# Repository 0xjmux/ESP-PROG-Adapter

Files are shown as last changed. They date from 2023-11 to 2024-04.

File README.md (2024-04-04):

# ESP32 Firmware Debugging, as Easy as Possible





* [My blog post about this project](https://jacobbokor.com/posts/esp-jtag-adapter/)
* [Look ma, I was featured on Hackaday!](https://hackaday.com/2024/04/03/esp-prog-adapter-makes-your-esp32-tinkering-seamless/)

One of the things I've noticed in a lot of beginner ESP32 PCBs is a lack of hardware debugging interfaces, which is understandable since setting up JTAG can be a bit confusing when you're first exposed to it. This project's goal is to make using JTAG and connector-less footprints on your PCBs as easy and cheap as possible. 

#### To get started, all you need is: 
1. An ESP-Prog, Espressif's cheap and flexible UART and JTAG adapter - [Aliexpress, ~$11 US](https://s.click.aliexpress.com/e/_DnkCFmz)
1. SOIC-8 Clip programming cable for SOICbite - [Aliexpress, ~$3](https://www.aliexpress.us/item/3256805091794484.html)
1. My adapter PCB and [connectors](#Components) ordered from your favorite PCB house ([Gerbers found under releases](https://github.com/0xjmux/ESP-PROG-Adapter/releases)) - ~$6 with connectors
1. My Kicad library (found under [ESP-EZ-Debug-KicadLib/](./ESP-EZ-Debug-KicadLib)) to easily include connector-less footprints in your Kicad designs. 

## ESP-Prog Programming Cable Adapter

Simple PCB that sits on top of the ESP-Prog to use the SOICbite and Tag-Connect TC2050-IDC adapters to program and debug ESP-based projects.
 
<p align="center">
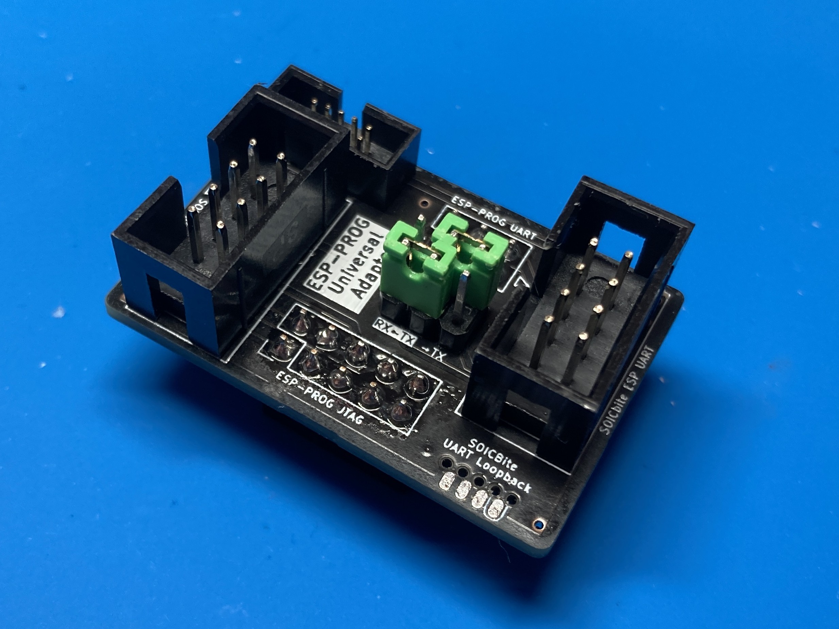
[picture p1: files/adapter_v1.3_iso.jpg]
ISO view of adapter

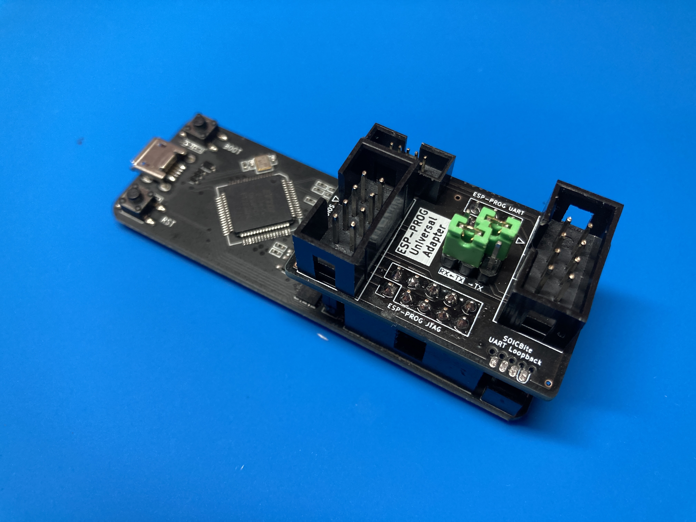
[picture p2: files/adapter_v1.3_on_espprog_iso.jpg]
ISO view of adapter on ESP-Prog

</p>

I originally made this adapter because I was in need of a hardware debugging solution for my ESP-based projects, and was tired of the dupont wire mess I needed to connect my programming cable to my JTAG adapter. 
 
## Features
* Easily connect your TC-2050-IDC and SOICbite programming cables to the ESP-Prog for JTAG and UART programming. 
    * This enables you to easily integrate component-less programming footprints with your ESP-based projects (and anything else using UART).
* Includes reversible UART TX/RX so if you mess it up on your board, you can easily change it on the adapter!
* Onboard SOICBite "loopback" footprint with TX-RX pins connected, allowing you to easily confirm your adapter's UART is working. 
* Detailed [schematic](files/esp-prog-adapter-v1.3-sch.pdf) containing all info you might need about the adapter, and easy to use schematic symbols (see [jmux-kicad-things](https://github.com/0xjmux/jmux-kicad-things)) for using the connectors in your designs. 

> [!NOTE]
> Schematic, Gerbers, and all other files needed for production and assembly can be found attached to the latest [release!](https://github.com/0xjmux/ESP-PROG-Adapter/releases/latest)

<p align="center">
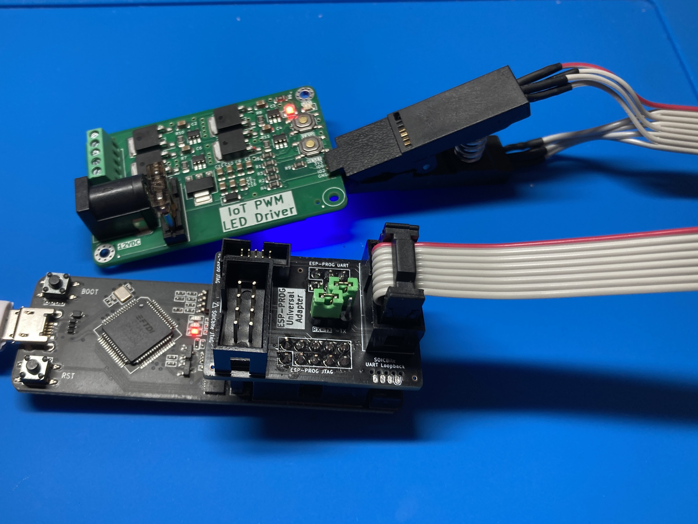
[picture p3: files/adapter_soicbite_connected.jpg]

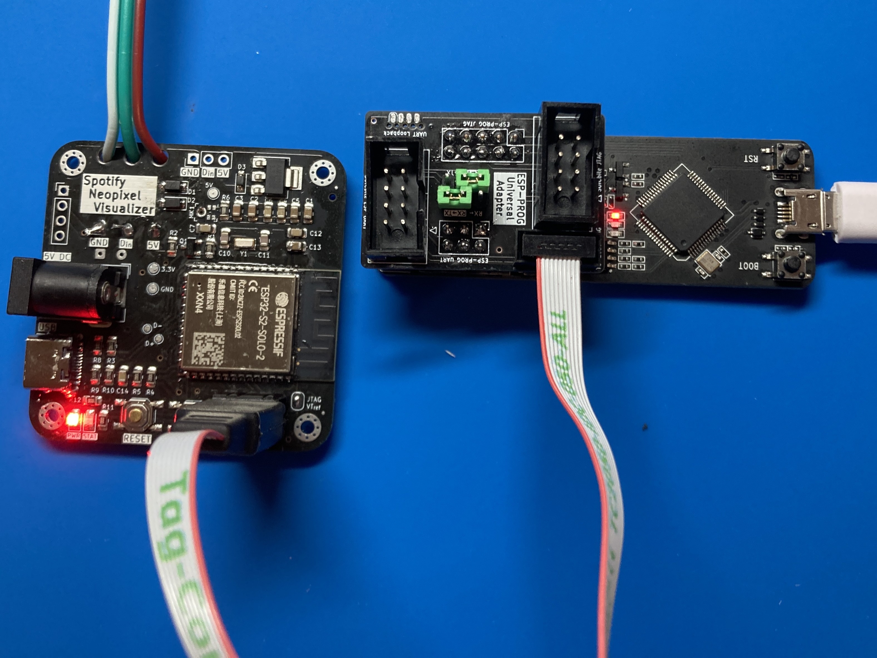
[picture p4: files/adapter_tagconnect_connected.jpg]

<br>SOICBite (left) and Tag-Connect (right) cables connected to target boards using the adapter
</p>

<p align="center">
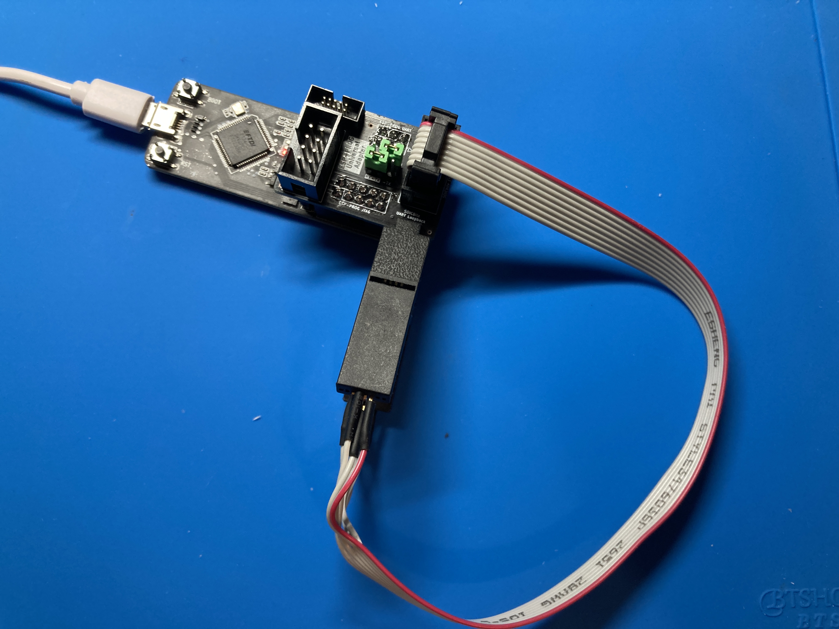
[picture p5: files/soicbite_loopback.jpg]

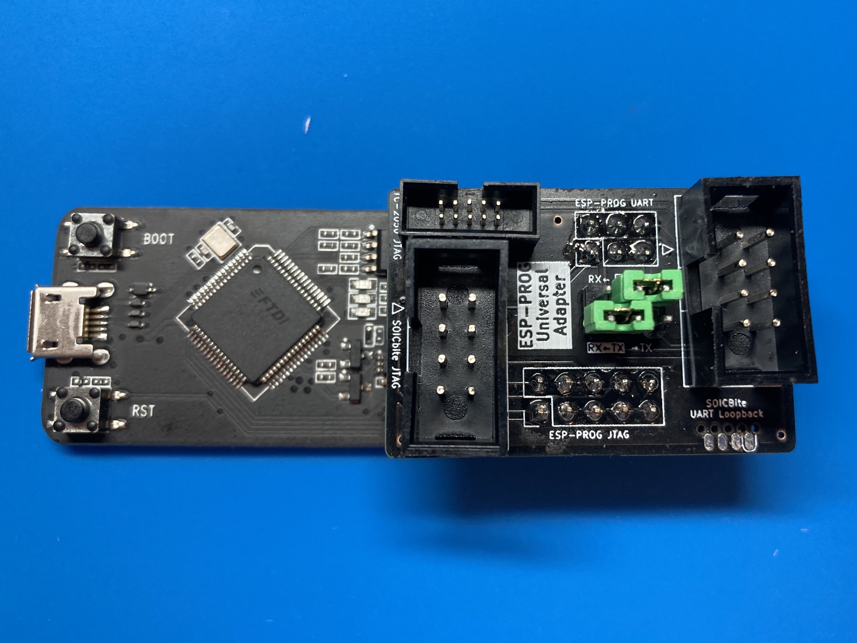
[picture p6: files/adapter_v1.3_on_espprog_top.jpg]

<br>SOICBite UART loopback usage (left) and top view of adapter on ESP-Prog (right)
</p>

## How to Use
* To make using these in your projects as easy as possible, I've created a Kicad library under `ESP-EZ-Debug-KicadLib/`. 
* These schematic symbols follow the [standard pinouts](https://github.com/SimonMerrett/SOICbite/tree/master?tab=readme-ov-file#pin-assignment) for each connector and are designed to be as self-explanatory as possible. There's an image example of connector wiring below, along with `UsageExamples.kicad_sch` so you can directly copy and paste into your designs. 

> [!NOTE]
> For information on installing and using the Kicad library, see [ESP-EZ-Debug-KicadLib/README.md](ESP-EZ-Debug-KicadLib/)

<p align="center">
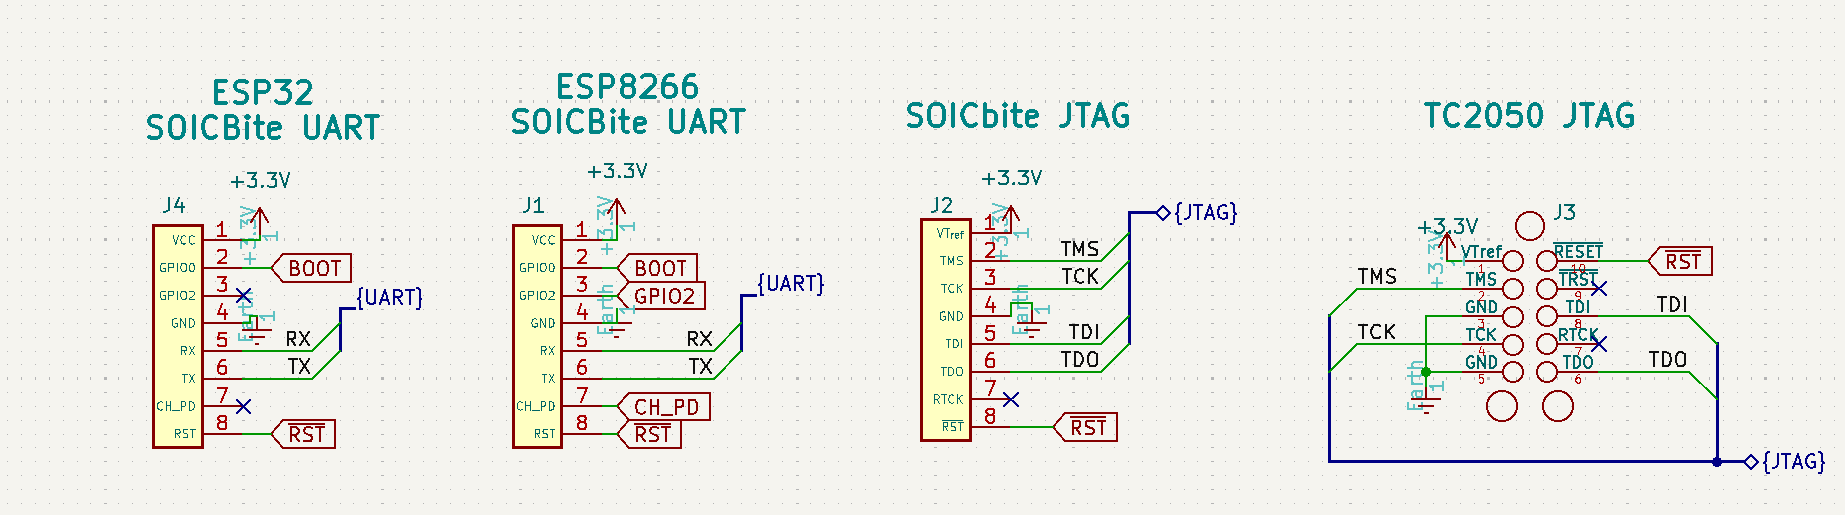
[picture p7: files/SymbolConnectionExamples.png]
<br>
Examples of how to wire up each connector to an ESP32
</p>

#### Pinouts
* The SOICBite UART connector follows the [standard pinout](https://github.com/SimonMerrett/SOICbite/tree/master?tab=readme-ov-file#pin-assignment). There wasn't a JTAG pinout already, so [I contributed one](https://github.com/SimonMerrett/SOICbite/pull/26) - although as of April 2024 it hasn't been merged into the repo. Because it hasn't been merged in, here's a pinout table. 

| Pin | ESP8266 | JTAG |
| --- | --- | ---- |
| 1 | Vcc | Vcc  |
| 2 | GPIO0 | TMS  |
| 3 | GPIO2 | TCK  |
| 4 | GND | GND  |
| 5 | RX | TDI  |
| 6 | TX | TDO  |
| 7 | CH_PD | RTCK |
| 8 | RST | NRST |

#### Software: Setting up Debugging with ESP-IDF and VSCode
* [This configuration note for the ESP-IDF VSCode extension](https://github.com/espressif/vscode-esp-idf-extension/blob/master/docs/DEBUGGING.md) is very helpful for setting up the IDE for hardware debugging
* [Espressif's documentation page on JTAG debugging for the ESP32](https://docs.espressif.com/projects/esp-idf/en/latest/esp32/api-guides/jtag-debugging/index.html#how-it-works)

## Hardware Setup/Soldering
The board comes with optional swappable UART jumpers. If this feature is not needed, simply solder the two solderjumpers (JP5 & JP6) that connect UART normally. 

> [!IMPORTANT]
> You must either bridge the solderjumpers or install the pin headers. If you don't do either, the UART interface won't be connected. 

### Components

| Component | Purpose | LCSC Part # | Link |
|---|---|---|---|
| 2x5P 2.54mm Female Header | ESP-Prog JTAG | C18723056 | [LCSC](https://www.lcsc.com/product-detail/Female-Headers_HanElectricity-2541FV-2x5P_C18723056.html) |
| 2x3P 2.54mm Female Header | ESP-Prog UART | C5298392 | [LCSC](https://www.lcsc.com/product-detail/span-style-background-color-ff0-Female-span-span-style-background-color-ff0-Headers-span_CJT-Changjiang-Connectors-A2541HWV-2x3P_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) |
| 2x5P 1.27mm IDC Header | TC2050 Conector | C2962228 | [LCSC](https://www.lcsc.com/product-detail/IDC-Connectors_XKB-Connectivity-X1270WV-2x05A-6TV01_C2962228.html) |
| 2x4P 2.54mm IDC Header (x2) | SOICBite Connector | C17179451 | [LCSC](https://www.lcsc.com/product-detail/IDC-Connectors_HanElectricity-HY2541WV-N-2x4P_C17179451.html) (x2) |
| 2x3P 2.54mm M Pin Header | Reversible UART Jumpers | C2935918 | [LCSC](https://www.lcsc.com/product-detail/Pin-Headers_DEALON-DZ254R-22-06-63_C2935918.html) |

<br/>
<p align="center" >
<br>
If you found the work I put into this valuable, I'd appreciate if you could buy me a coffee so I can continue devoting time to extensively documenting my projects like this. 
</p>

### Soldering Order
I recommend going from shortest to tallest components, starting on the top side of the PCB. This is a very approachable solder job since everything is THT, but when attaching the headers that connect to the ESP-PROG there is the potential to burn the plastic of the connectors already installed on the top. Here's the order I recommend attaching the components:

1. TC2050 IDC Socket
1. 2x3 Pin header and SOICbite socket(s)
1. Downward facing F pin headers that connect to ESP-PROG

## Versions
### V1.4 - Polishing it up
* All functionality confirmed working.
* PCB updated to clarify assembly and use (text enlarged, dual 1x3 headers for reversible UART changed to single 2x3P using custom symbol).
* Vdd for JTAG and UART disconnected from each other on adapter, allowing different voltage to be used for each.
* Connected nRST line of ESP-PROG (from UART header) to board RESET line on JTAG pinout with solderjumper.
* Default connected solderjumpers changed to default open for Reversible UART, since I anticipate it'll be more used than not. 

<p align="center">
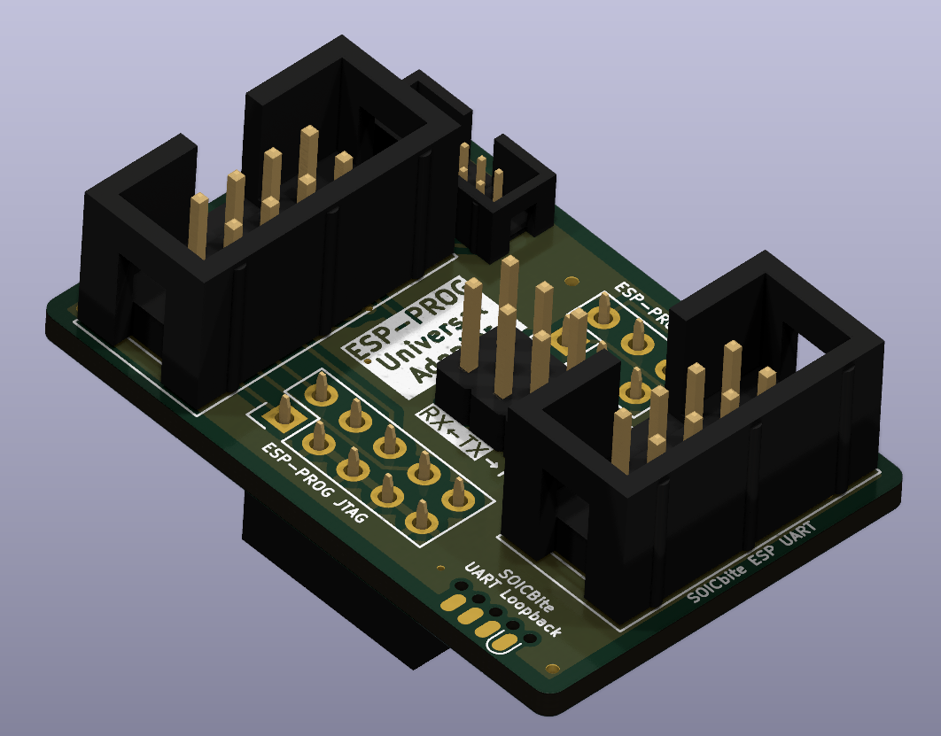
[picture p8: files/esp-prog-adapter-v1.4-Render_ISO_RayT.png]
v1.4 PCB Render ISO angle

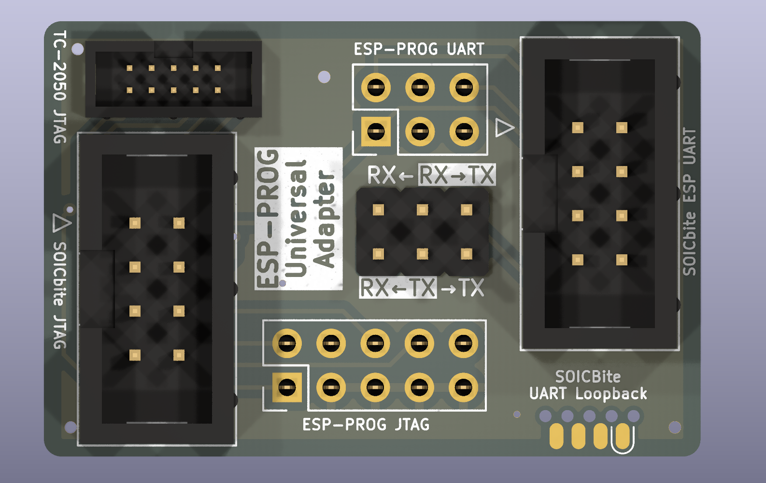
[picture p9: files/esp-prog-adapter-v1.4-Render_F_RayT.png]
v1.4 PCB Render Front

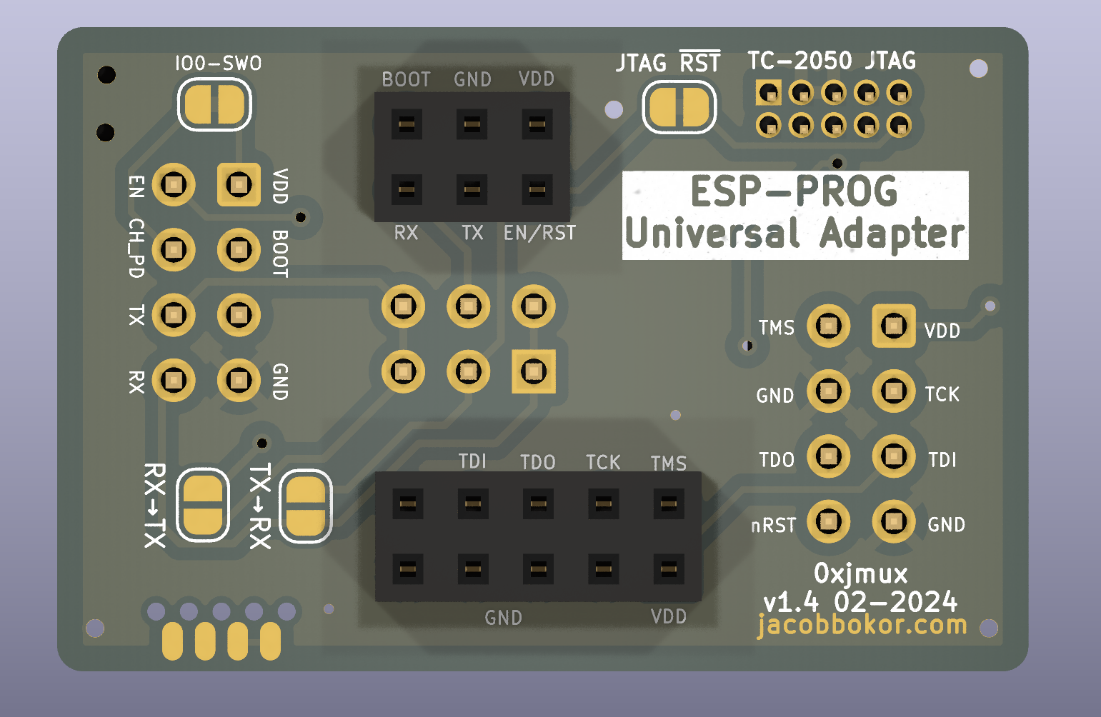
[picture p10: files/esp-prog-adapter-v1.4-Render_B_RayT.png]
v1.4 PCB Render Back

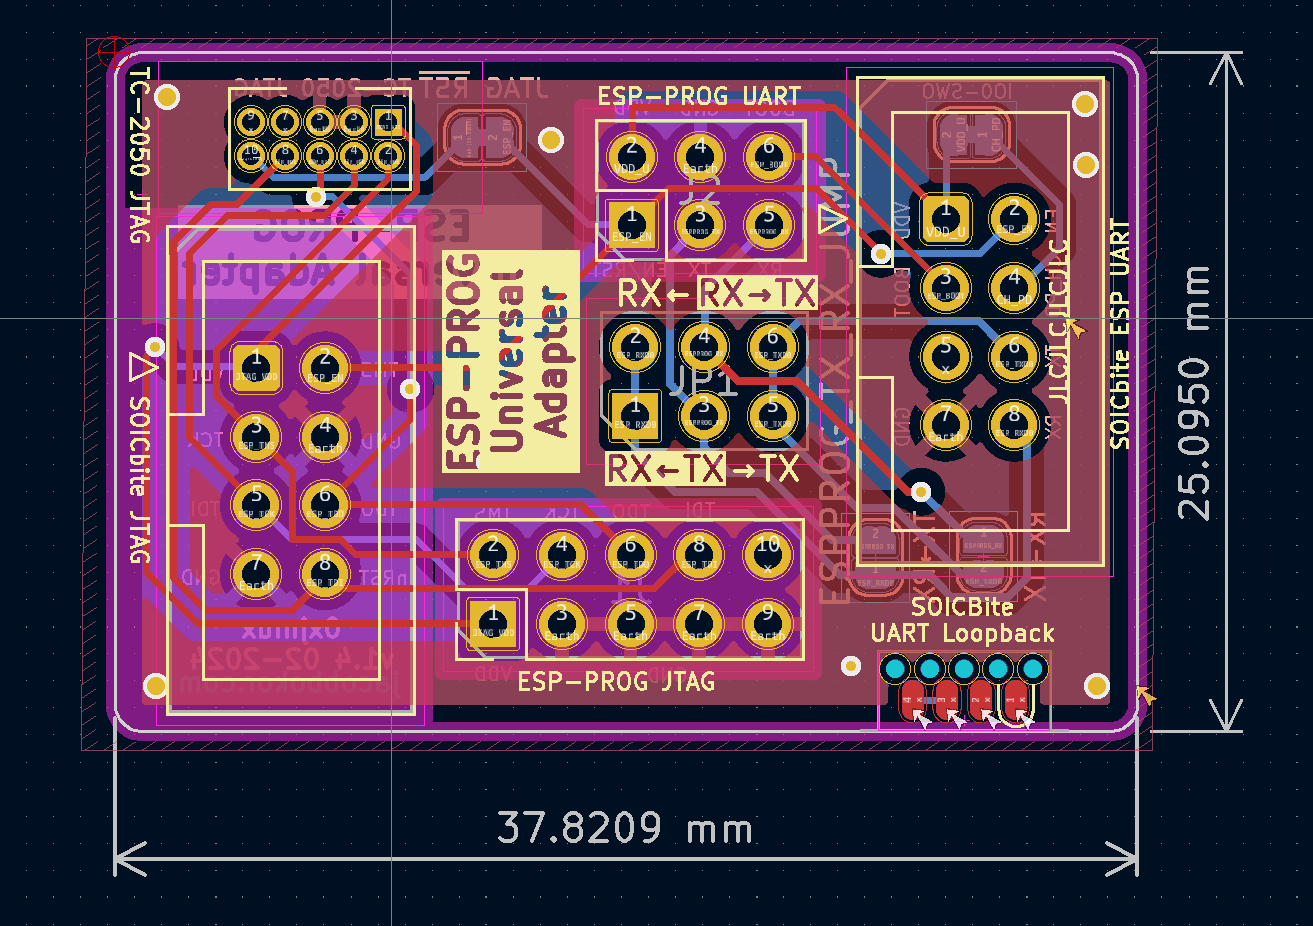
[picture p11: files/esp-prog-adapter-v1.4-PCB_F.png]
v1.4 PCB Layout

</p>

---

### V1.3 - Redesigned (Again)
* Added headers that allow you to easily reverse UART TX-RX in case it was mixed up on the board you're testing. Just cut the solderjumpers on the bottom of the board, add header pins to the top, and the direction is now easily changeable. The bolded text indicates the default direction. 
* Fix symbol and footprint orientation for SOICbite from 1.2. Removed the TC2050 UART connector.
* Added a SOICbite connector on the side of the board with TX-RX pins connected together, allowing you to test that the adapter & drivers are working correctly via UART loopback. 
* Added notes to the schematic to make pinouts clear for anyone reading it, so similar symbol/footprint orientation mistakes aren't made again.
 
<p align="center">
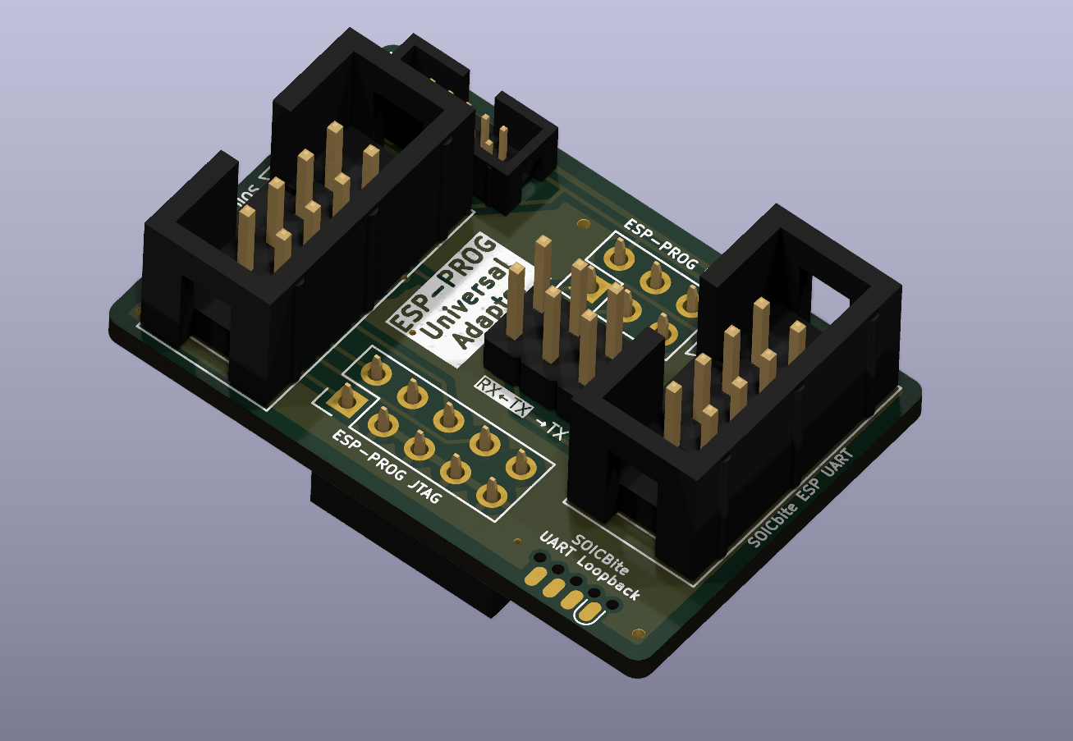
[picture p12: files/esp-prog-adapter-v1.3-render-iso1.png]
v1.3 PCB Render Back

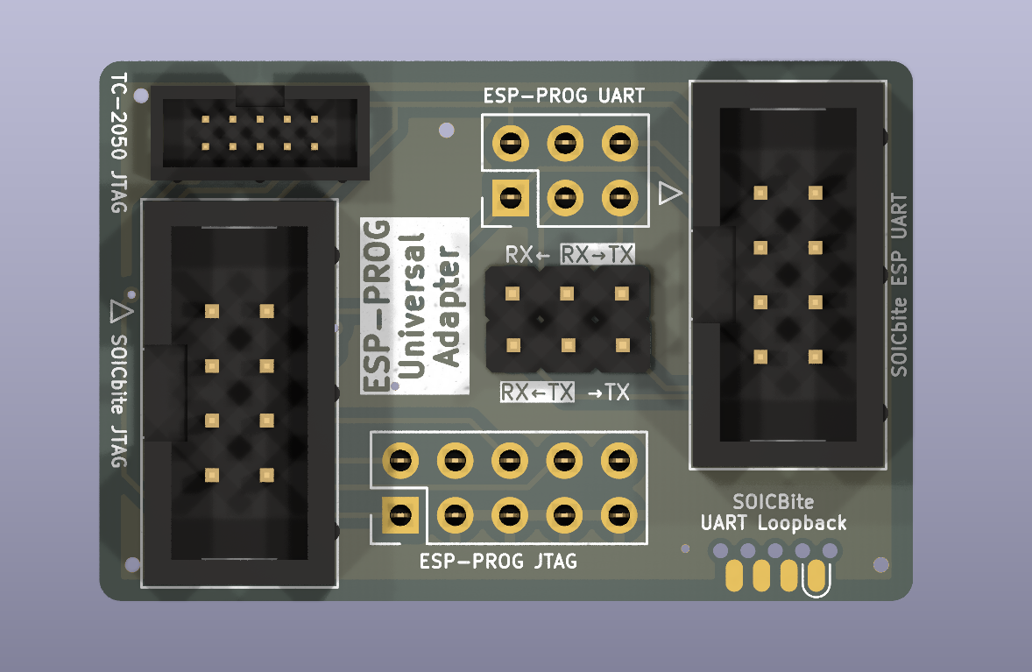
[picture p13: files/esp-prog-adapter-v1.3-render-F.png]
v1.3 PCB Render Front

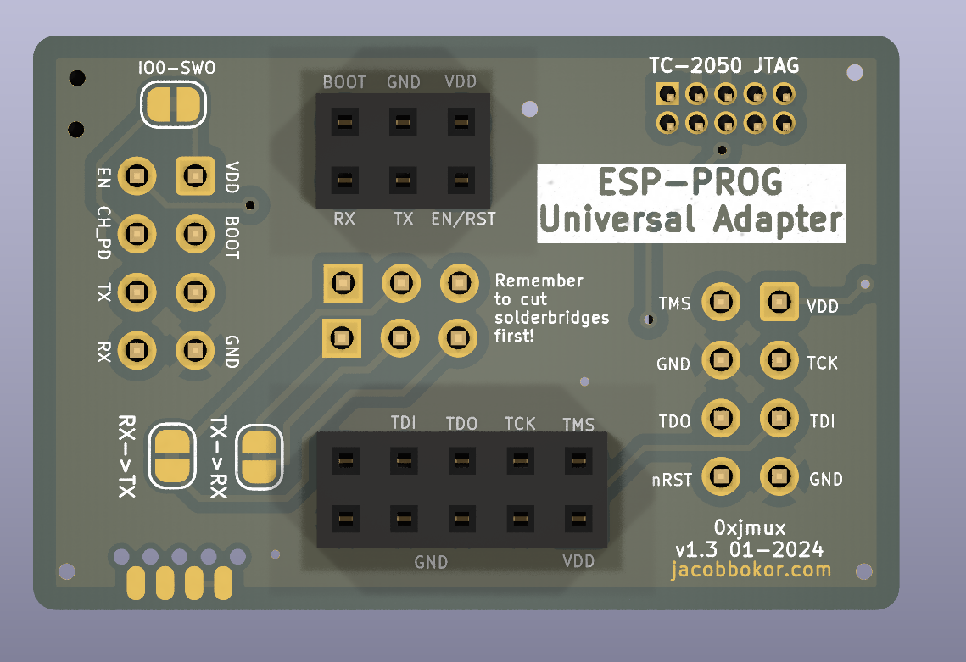
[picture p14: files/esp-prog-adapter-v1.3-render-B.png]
v1.3 PCB Render Back

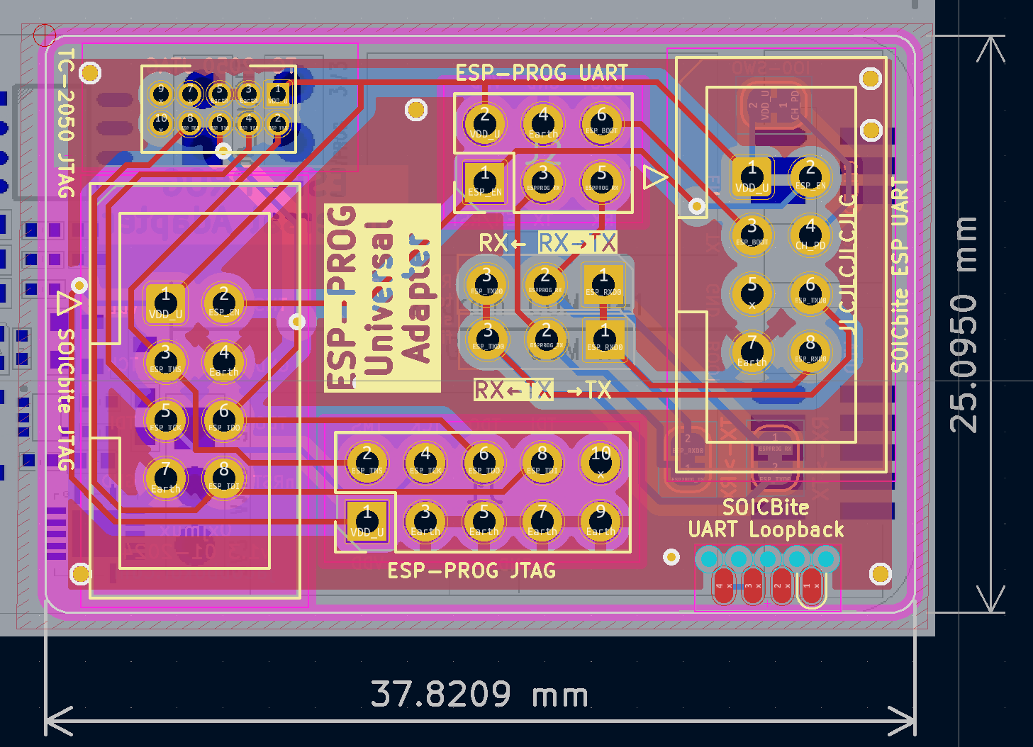
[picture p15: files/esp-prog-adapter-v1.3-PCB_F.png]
v1.3 PCB Layout

</p>
 
---

### V1.2 - JTAG arrives!
* Added JTAG compatibility headers, extended size of board. 
* The time between designing and ordering this version was on the order of months. Once I ordered it, I realized I had mixed up the pin ordering on the footprints, and needed to modify the schematic. 
* SOICbite connector wasn't oriented right. 

<p align="center">
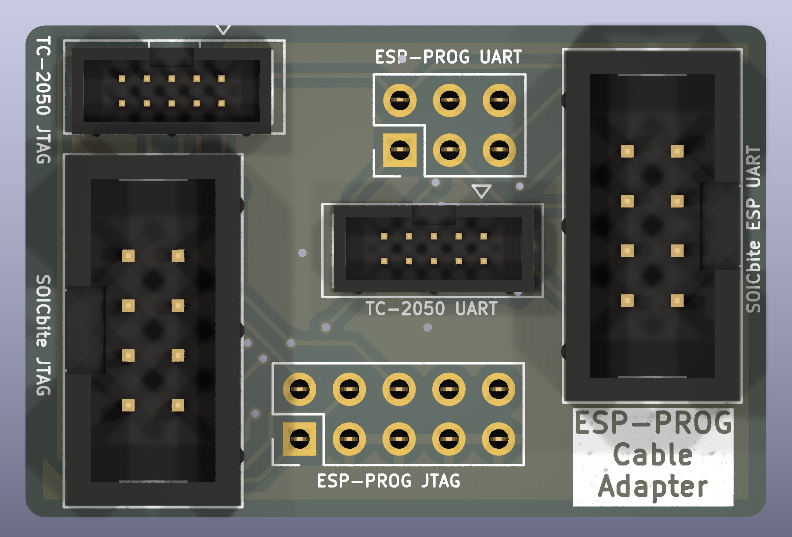
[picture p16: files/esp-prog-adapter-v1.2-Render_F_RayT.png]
v1.2 PCB Render Front

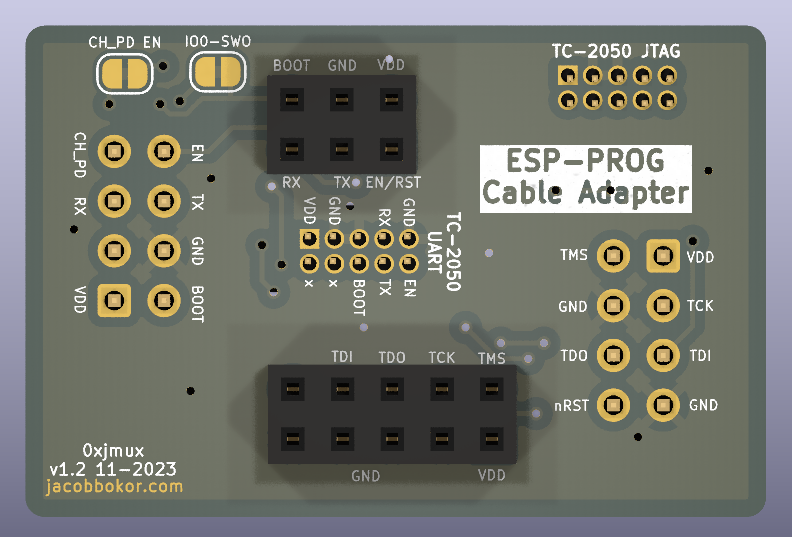
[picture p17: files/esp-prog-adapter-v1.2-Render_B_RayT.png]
v1.2 PCB Render Back

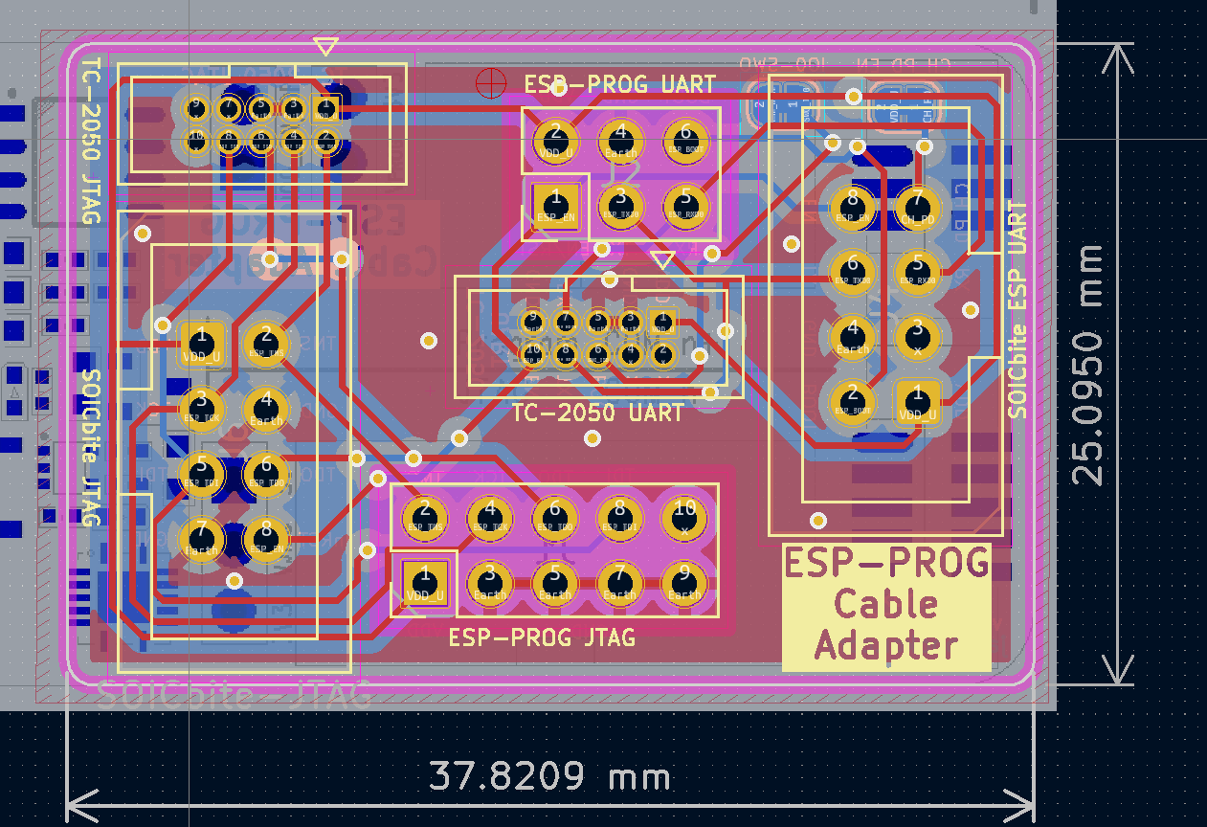
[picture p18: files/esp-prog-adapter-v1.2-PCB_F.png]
v1.2 PCB Layout

</p>

---

## References
* This project was inspired by BrechtVE's very cool [Universal J-Link adapter](https://github.com/Fescron/universal-jlink-adapter), which I was originally planning on using. Segger's discontinuation of the J-Link EDU left me in search of other options since the EDU mini doesn't support the ESP's Xtensa LX7 architecture, which is how I landed on the ESP-Prog.

---

The goal here is to make the joy of firmware debugging as easy to approach as possible; if you have any suggestions, please feel free to open a PR. 

<br>
<p align="center">
<br>
</p>

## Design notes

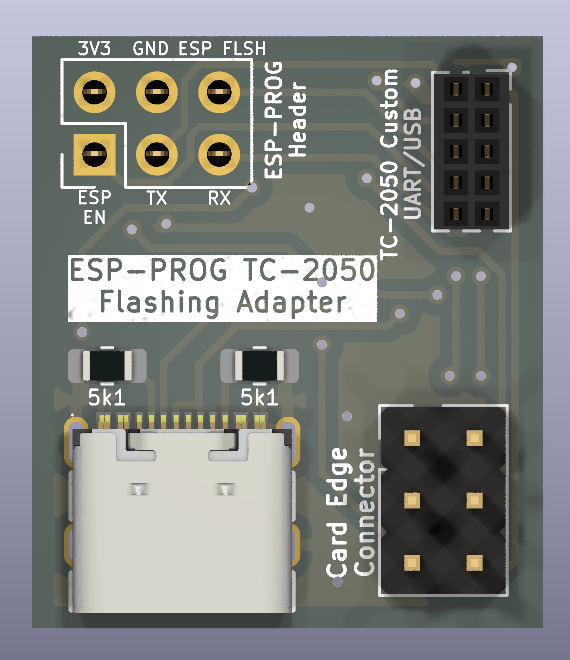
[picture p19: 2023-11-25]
files/esp-prog-adapter-v1.0-render_F_RayT.png

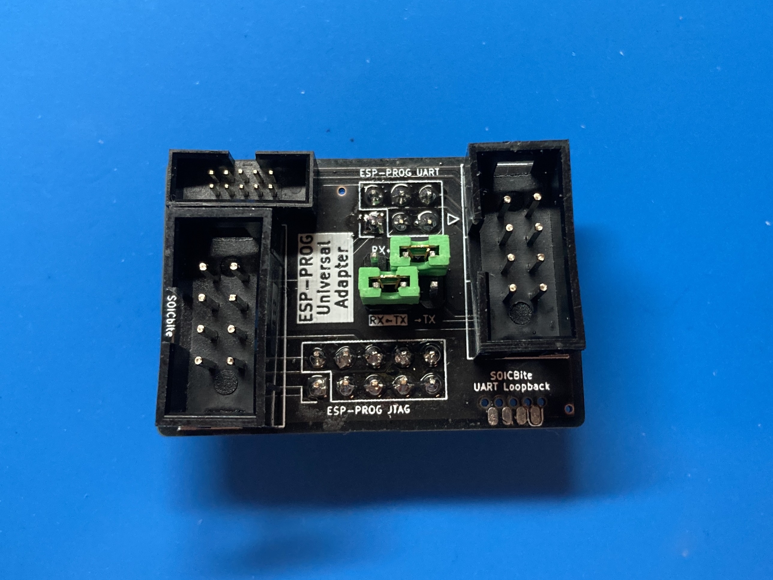
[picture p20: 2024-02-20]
files/adapter_v1.3_top.jpg

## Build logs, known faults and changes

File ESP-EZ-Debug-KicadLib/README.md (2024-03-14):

# ESP-EZ-Debug Library

This is a quick library I threw together to make adding this to Kicad projects as easy as possible. 

Simply download the repo, and [follow these instructions from Kicad to install them](https://docs.kicad.org/7.0/en/getting_started_in_kicad/getting_started_in_kicad.html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)

### Example Usage
Example wiring for each connector

#### A note on SOICbite
I have also included the [SOICBite](https://github.com/SimonMerrett/SOICbite) kicad footprint in this repo for ease of use.

The awesome SOICbite footprint was created by [Simon Merrett](https://github.com/SimonMerrett) and is licensed under BSD-2. A copy of the BSD 2-Clause license can be found in `footprints/` next to the SOICbite footprint, `SOIC_clipProgSmall.kicad_mod`. The original SOICbite footprint can be found directly [here](https://github.com/SimonMerrett/SOICbite/blob/master/SOIC_clipProgSmall.kicad_mod), and you should go give that repo a like; this one wouldn't have been possible without it. 

Simon's repo also includes [instructions on modifying your SOIC clip connector](https://github.com/SimonMerrett/SOICbite/blob/master/HOWTO_mod_clip.md), which is needed before you can use it as a programming connector. 

#### Tag-Connect Symbols and Footprints
* The TC2050 footprint should already be in Kicad's `Connector` footprint library by default. If not, download and install nawotech's [kicad-tag-connect](https://github.com/nawotech/kicad-tag-connect) library.

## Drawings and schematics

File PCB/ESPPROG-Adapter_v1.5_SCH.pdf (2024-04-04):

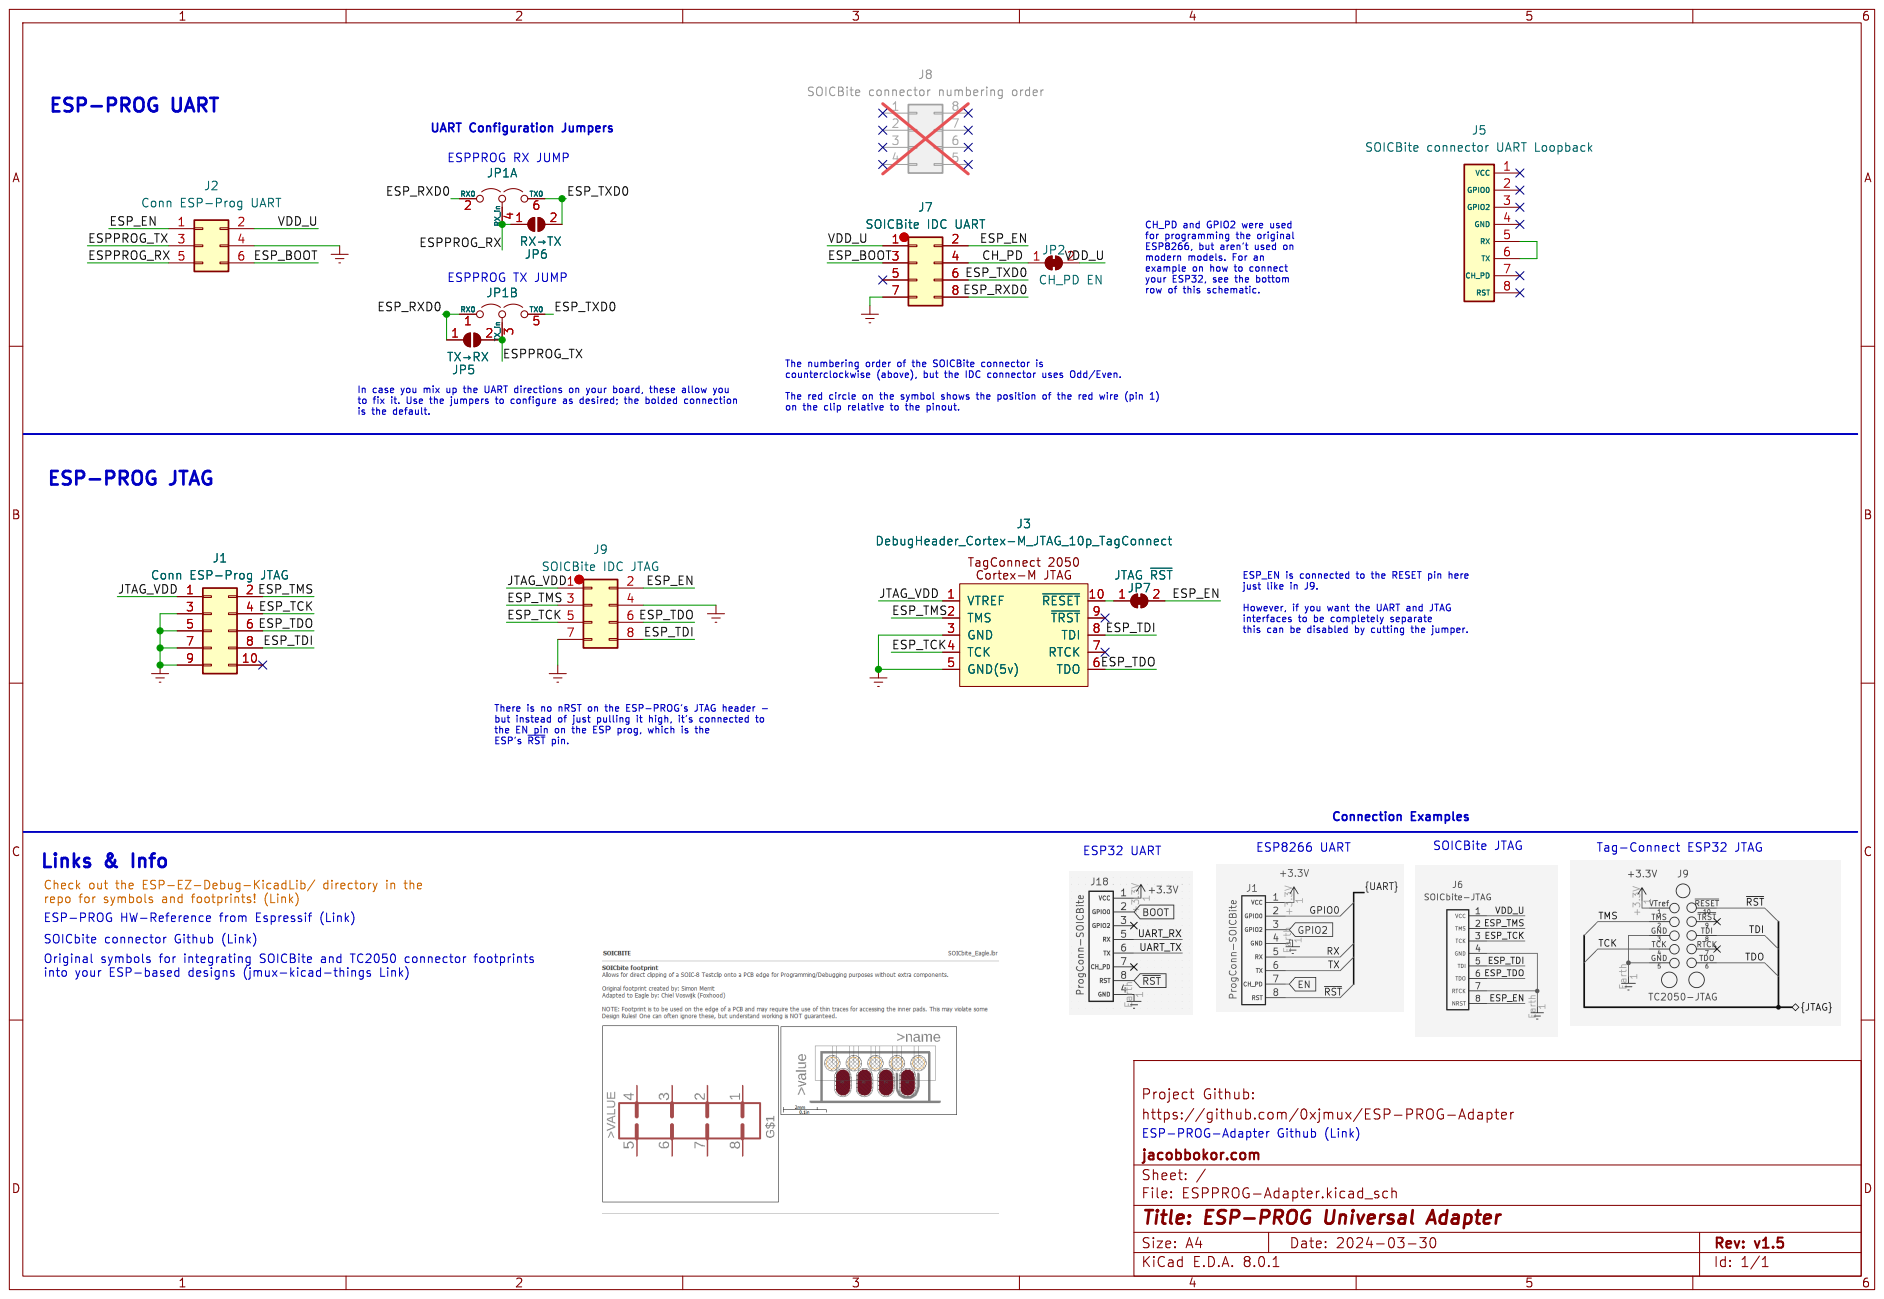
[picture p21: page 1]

row of this schematic. J7 SOICBite IDC UART

example on how to connect your ESP32, see the bottom

just like in J9. However, if you want the UART and JTAG

Project Github:
https://github.com/0xjmux/ESP-PROG-Adapter

jacobbokor.com
Id: 1/1 Title: ESP-PROG Universal Adapter File: ESPPROG-Adapter.kicad_sch Sheet: /

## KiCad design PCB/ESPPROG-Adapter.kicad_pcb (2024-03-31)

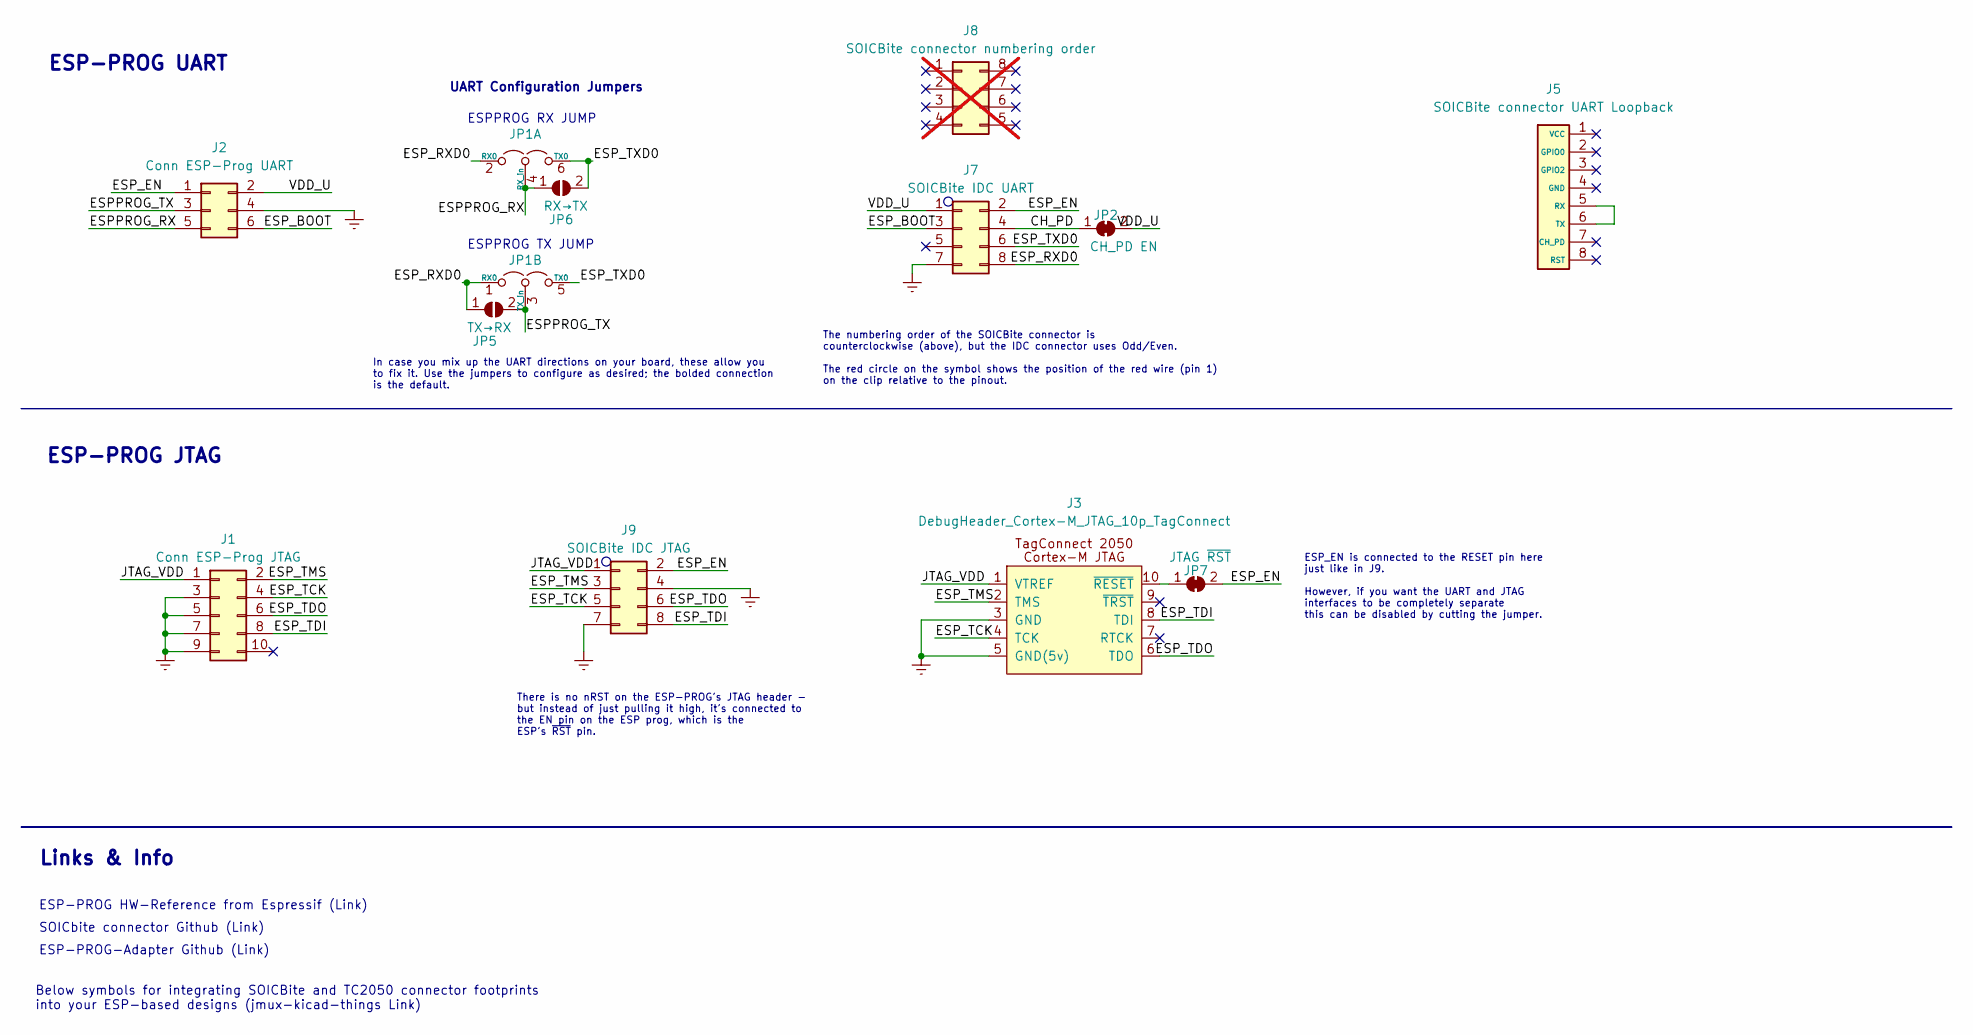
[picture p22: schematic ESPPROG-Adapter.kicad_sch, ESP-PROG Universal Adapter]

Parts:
J1: Conn ESP-Prog JTAG; PinSocket_2x05_P2.54mm_Vertical; LCSC C18723056
J2: Conn ESP-Prog UART; PinSocket_2x03_P2.54mm_Vertical; LCSC C5298392
J3: DebugHeader_Cortex-M_JTAG_10p_TagConnect; TC-2050-IDC-SOCKET; LCSC C2962228
J5: SOICBite connector UART Loopback; SOIC_clipProgSmall
J7: SOICBite IDC UART; IDC-Header_2x04_P2.54mm_Vertical; LCSC C17179451
J8: SOICBite connector numbering order; not fitted
J9: SOICBite IDC JTAG; IDC-Header_2x04_P2.54mm_Vertical; LCSC C17179451
JP1: ESPPROG_TX_RX_JUMP; PinHeader_2x03_P2.54mm_Vertical; LCSC C2935918
JP2: CH_PD EN; SolderJumper-2_P1.3mm_Bridged_RoundedPad1.0x1.5mm
JP5: TX→RX; SolderJumper-2_P1.3mm_Open_RoundedPad1.0x1.5mm
JP6: RX→TX; SolderJumper-2_P1.3mm_Open_RoundedPad1.0x1.5mm
JP7: JTAG ~{RST}; SolderJumper-2_P1.3mm_Bridged_RoundedPad1.0x1.5mm

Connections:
/CH_PD: J7.4, JP2.1 (A)
/ESPPROG_RX: J2.5, JP1.4 (RX_in), JP6.1 (A)
/ESPPROG_TX: J2.3, JP1.3 (TX_in), JP5.2 (B)
/ESP_BOOT: J2.6, J7.3
/ESP_EN: J2.1, J7.2, J9.2, JP7.2 (B)
/ESP_RXD0: J7.8, JP1.1 (RX0), JP1.2 (RX0), JP5.1 (A)
/ESP_TCK: J1.4, J3.4 (TCK), J9.5
/ESP_TDI: J1.8, J3.8 (TDI), J9.8
/ESP_TDO: J1.6, J3.6 (TDO), J9.6
/ESP_TMS: J1.2, J3.2 (TMS), J9.3
/ESP_TXD0: J7.6, JP1.5 (TX0), JP1.6 (TX0), JP6.2 (B)
/JTAG_VDD: J1.1, J3.1 (VTREF), J9.1
/VDD_U: J2.2, J7.1, JP2.2 (B)
Earth: J1.3, J1.5, J1.7, J1.9, J2.4, J3.3 (GND), J3.5 (GND(5v)), J7.7, J9.4, J9.7
unnamed: J3.10 (~RESET), JP7.1 (A)
unnamed: J5.5 (RX), J5.6 (TX)

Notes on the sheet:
UART Configuration Jumpers
ESP-PROG JTAG
SOICbite connector Github (Link)
ESP-PROG-Adapter Github (Link)
Below symbols for integrating SOICBite and TC2050 connector footprints into your ESP-based designs (jmux-kicad-things Link)
Links & Info
ESPPROG RX JUMP
ESP-PROG HW-Reference from Espressif (Link)
ESP-PROG UART
In case you mix up the UART directions on your board, these allow you to fix it. Use the jumpers to configure as desired; the bolded connection is the default.
There is no nRST on the ESP-PROG's JTAG header - but instead of just pulling it high, it's connected to the EN pin on the ESP prog, which is the ESP's ~{RST} pin.
The numbering order of the SOICBite connector is counterclockwise (above), but the IDC connector uses Odd/Even. The red circle on the symbol shows the position of the red wire (pin 1) on the clip relative to the pinout.
ESP_EN is connected to the RESET pin here just like in J9. However, if you want the UART and JTAG interfaces to be completely separate this can be disabled by cutting the jumper.
ESPPROG TX JUMP

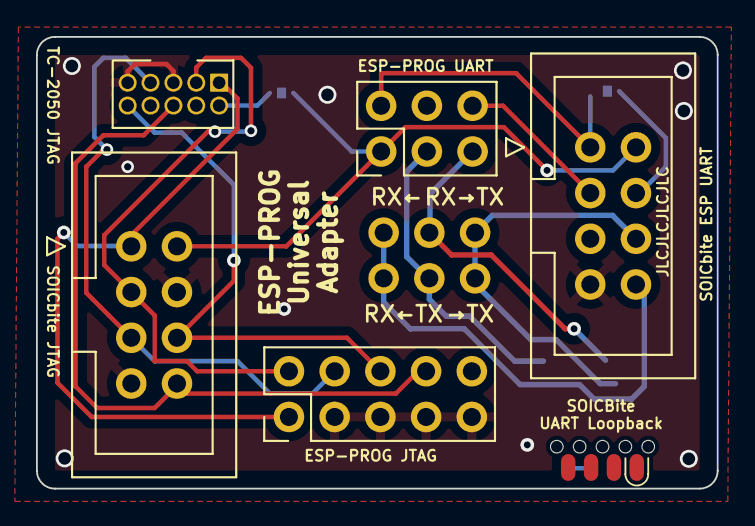
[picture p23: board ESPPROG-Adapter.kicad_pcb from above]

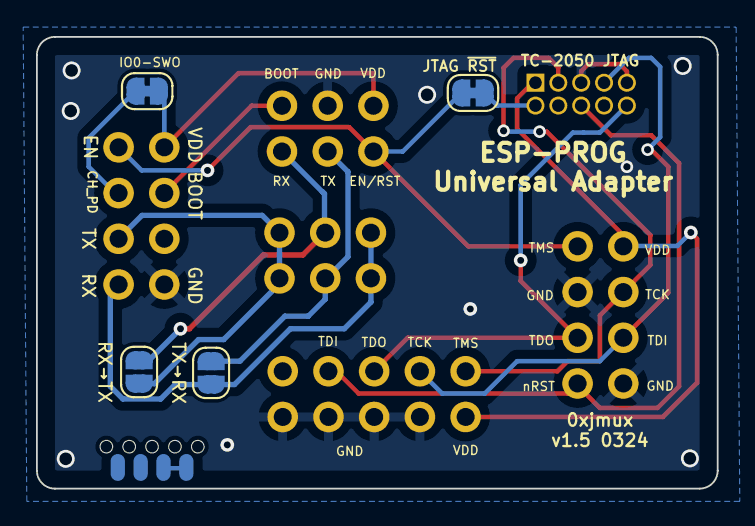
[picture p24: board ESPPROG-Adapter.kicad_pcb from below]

Board: 2 copper layers, 37.8 x 25.1 mm, 11 parts (5 on the bottom side), 16 nets.

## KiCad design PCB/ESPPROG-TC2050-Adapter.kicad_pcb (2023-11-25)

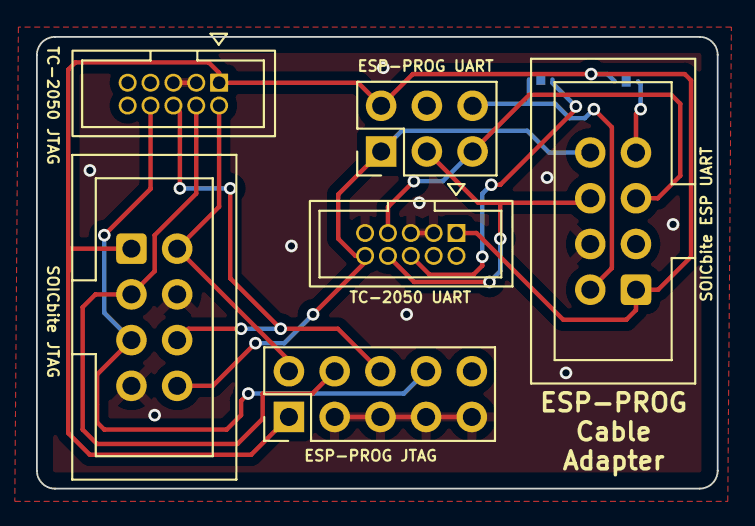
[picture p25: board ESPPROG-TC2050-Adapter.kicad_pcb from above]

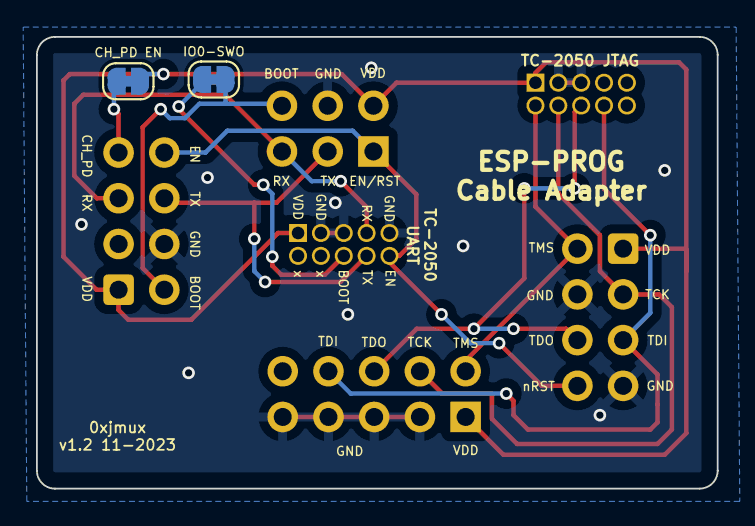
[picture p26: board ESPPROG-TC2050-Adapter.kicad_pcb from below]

Board: 2 copper layers, 37.8 x 25.1 mm, 8 parts (3 on the bottom side), 12 nets.

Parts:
J1: Conn_02x05_Odd_Even; PinSocket_2x05_P2.54mm_Vertical
J2: CONN ESP-PROG; PinSocket_2x03_P2.54mm_Vertical
J3: DebugHeader_Cortex-M_JTAG_10p_TagConnect; TC-2050-IDC-SOCKET
J4: ProgConn-SOICBite; IDC-Header_2x04_P2.54mm_Vertical
J5: DebugHeader_Cortex-M_SWD_UART_10p_TagConnect; TC-2050-IDC-SOCKET
J6: SOICbite-JTAG; IDC-Header_2x04_P2.54mm_Vertical
JP1: CH_PD EN; SolderJumper-2_P1.3mm_Bridged_RoundedPad1.0x1.5mm
JP2: SolderJumper_2_Bridged; SolderJumper-2_P1.3mm_Bridged_RoundedPad1.0x1.5mm

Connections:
/CH_PD: J4.7 (CH_PD), JP1.1 (A)
/ESP_BOOT: J2.6, J4.2 (GPIO0), JP2.2 (B)
/ESP_EN: J2.1, J4.8 (RST), J5.10 (~RESET), J6.8 (NRST)
/ESP_RXD0: J2.5, J4.5 (RX), J5.7 (jl.RX(nc))
/ESP_TCK: J1.4, J3.4 (TCK), J6.3 (TCK)
/ESP_TDI: J1.8, J3.8 (TDI), J6.5 (TDI)
/ESP_TDO: J1.6, J3.6 (TDO), J6.6 (TDO)
/ESP_TMS: J1.2, J3.2 (TMS), J6.2 (TMS)
/ESP_TXD0: J2.3, J4.6 (TX), J5.8 (jl.TX(nc))
/SWO_IO0: J5.6 (SWO), JP2.1 (A)
/VDD_U: J1.1, J2.2, J3.1 (VTREF), J4.1 (VCC), J5.1 (VTREF), J6.1 (VCC), JP1.2 (B)
Earth: J1.3, J1.5, J1.7, J1.9, J2.4, J3.3 (GND), J3.5 (GND(5v)), J4.4 (GND), J5.3 (GND), J5.5 (GND(5v)), J5.9 (GNDd(nc)), J6.4 (GND), J6.7 (RTCK)

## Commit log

2023-11-06 initial commit and v1.0
    [ESPPROG-TC2050-Adapter.kicad_pcb, ESPPROG-TC2050-Adapter.kicad_sch]
2023-11-25 Majority of v1.1 changes
    * Removed card-edge connector
    * Added SOICbite 2x4P 2.54mm header with ESP8266 pinout
    * changed TC-2050 pinout to more default UART one
    * changed board dimensions to better fit on top of ESP-PROG
    * added to-scale picture of ESP-PROG in background to get better feel
    for alignment
    [ESPPROG-TC2050-Adapter.kicad_pcb, ESPPROG-TC2050-Adapter.kicad_sch]
2023-11-25 updated BOM fields and added LCSC PNs
    [ESPPROG-TC2050-Adapter.kicad_sch]
2023-11-25 Redesign for v1.2
    * Added second F header to connect to ESP-PROG's JTAG header
    * added connectors for TC2050 and SOICbite for JTAG
    * had to extend board length as a result
    [ESPPROG-TC2050-Adapter.kicad_pcb, ESPPROG-TC2050-Adapter.kicad_sch]
2023-11-25 reorganized repo and added accompanying files
    [ESPPROG-TC2050-Adapter.kicad_pcb, ESPPROG-TC2050-Adapter.kicad_sch]
2024-01-31 nothing major, just a complete redesign for v1.3
    [ESPPROG-Adapter.kicad_pcb, ESPPROG-Adapter.kicad_sch, ESPPROG-TC2050-Adapter.kicad_sch]
2024-02-06 readme update
    [ESPPROG-Adapter.kicad_sch]
2024-02-20 Writeup and minor changes for v1.4
    v1.3 arrived and all functionality was confirmed working. This commit
    adds the writeup, license, and some small modifications to the PCB to
    make it a little easier to use.
    * PCB updated to clarify assembly and use (text enlarged, dual 1x3 headers for reversible UART changed to single 2x3P using custom symbol).
    * Vdd for JTAG and UART disconnected from each other on adapter, allowing different voltage to be used for each.
    * Connected nRST line of ESP-PROG (from UART header) to board RESET line on JTAG pinout with solderjumper.
    * Default connected solderjumpers changed to default open for Reversible UART, since I anticipate it'll be more used than not.
    [ESPPROG-Adapter.kicad_pcb, ESPPROG-Adapter.kicad_sch]
2024-02-23 added Project Library with Symbols, updated README
    [UsageExamples.kicad_sch]
2024-03-14 README updates, library renamed, readability updates on board
    [ESPPROG-Adapter.kicad_pcb, ESPPROG-Adapter.kicad_sch]
2024-03-31 v1.5 TC2050 pinout change
    [ESPPROG-Adapter.kicad_pcb, ESPPROG-Adapter.kicad_sch]
2024-04-04 Clarification and new example added to SCH, links in library updated
    * added link to hackaday article
    * added clarification about CH_PD and GPIO2 to SCH
    * Added example of ESP32 UART to SCH
    * Added pinout table to README
    * Updated example schematic
    * replaced connector wiring example png with updated version
    [ESPPROG-Adapter.kicad_sch, UsageExamples.kicad_sch]

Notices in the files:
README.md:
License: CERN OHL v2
